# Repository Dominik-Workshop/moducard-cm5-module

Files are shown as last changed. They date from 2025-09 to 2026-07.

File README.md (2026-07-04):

# ModuCard CM5 module

 

<p align="center">
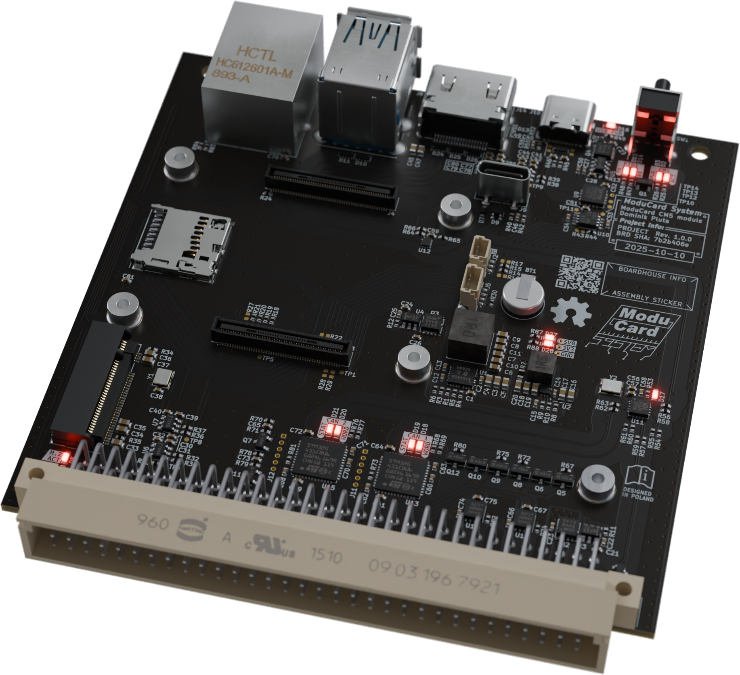
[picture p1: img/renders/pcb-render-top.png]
PCB render top
  
</p>

## Overview

The **ModuCard CM5 Module** is a carrier board for the **Raspberry Pi Compute Module 5**.
It is designed to interface with the  [ModuCard backplane](https://github.com/KoNarRobotics/ModuCard-backplane), to create a more complex electronics system.

The module breaks out selected CM5 interfaces to front-panel connectors and it interfaces with the backplane.

### Key Features

- **Networking:** Gigabit Ethernet (RJ45)
- **Connectivity:** 2x USB 3.0 Type-A ports
- **Display:** 1x Full-size HDMI port
- **Storage:**
  - **Micro SD** card slot (for CM5 Lite variants)
  - **M.2 M-Key** slot (PCIe x1 Gen 3) for NVMe SSDs or AI accelerators.
- **System & Debug:**
  - **USB-C** port (front panel) for serial console access
  - **USB-C** port (vertical) for flashing the CM5 via `rpiboot`.
- **Backplane I/O:**
  - 2x **FD CAN** interfaces with on-board transceivers
  - 1x **USB 2.0**
- **Cooling:** 4-pin JST connector for the CM5 cooling fan.

<p align="center">
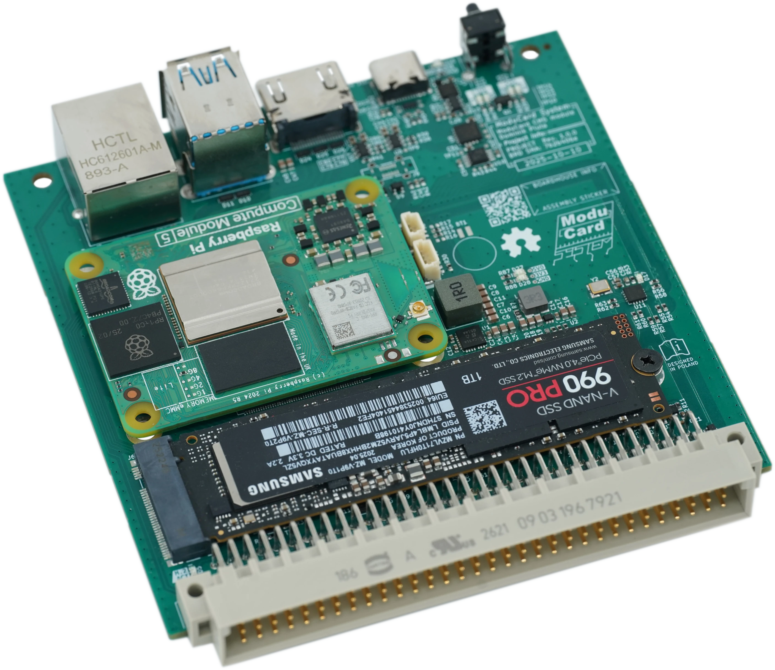
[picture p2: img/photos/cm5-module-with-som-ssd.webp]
Assembled ModuCard CM5 module
  
  <br>
  <em>Assembled ModuCard CM5 Module with Raspberry Pi Compute Module 5 and NVMe SSD.</em>
</p>

## Project Status

**Design:** ✅ → **Fabrication & Assembly:** ✅ → **Bring-up:** ✅

The project is **complete and ready for deployment**. All core features have been validated on physical hardware.

## Used Tools

- [KiCad](https://www.kicad.org/) - Schematic and PCB design

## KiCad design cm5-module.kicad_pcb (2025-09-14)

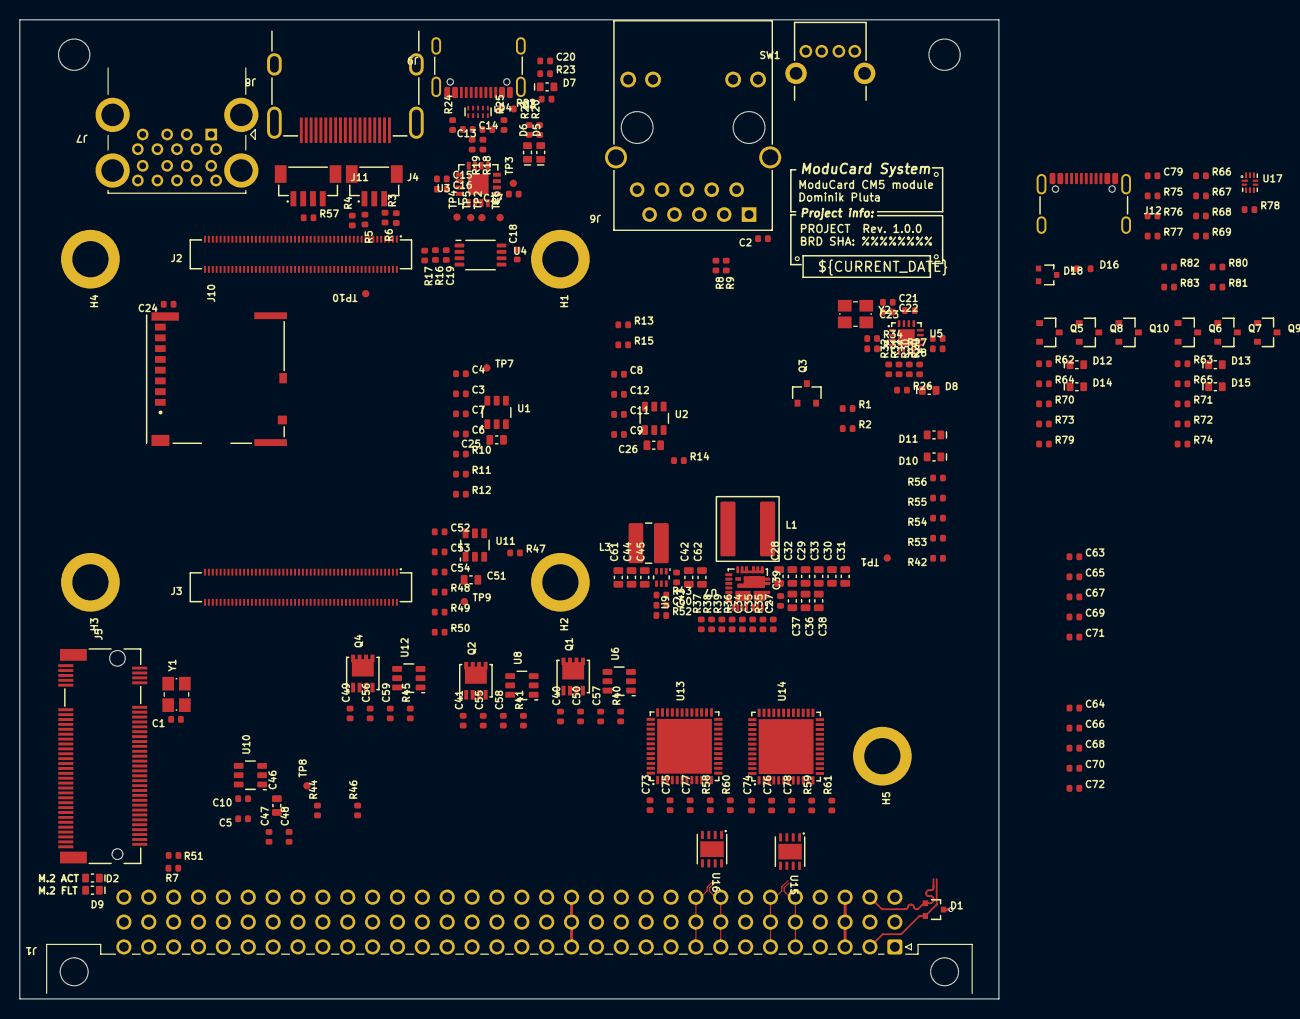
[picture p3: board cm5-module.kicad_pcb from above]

Board: 4 copper layers, 100.0 x 100.0 mm, 240 parts (0 on the bottom side), 205 nets.

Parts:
A1: RPi CM5; CM5
A2: M.2 M-key 2280; Card_M.2-2280-M-key
C1, C2, C3, C4, C5, C8, C9, C16, C17, C18, C19, C20, C22, C24, C27, C39, C40, C41, C43, C48, C49, C50, C54, C55, C56, C57, C58, C59, C63, C64, C65, C66, C67, C68, C69, C70, C71, C72, C73, C74, C75, C76, C77, C78, C79: C-100n-0402; C_0402_1005Metric
C6, C7, C10, C11, C12, C15, C21, C23, C34, C47, C52, C53: C-4u7-0402; C_0402_1005Metric
C13, C14, C60: C-47p-0402; C_0402_1005Metric
C25, C26, C28, C29, C30, C31, C32, C33, C36, C37, C38, C42, C44, C45, C46, C51, C61, C62: C-10u-0603; C_0603_1608Metric
C35: C-1u-0402; C_0402_1005Metric
D1, D18: TPD2E2U06DCKR; SOT-323
D2, D5, D6, D7, D8, D9, D10, D11, D12, D13, D14, D15: LED-R-0603_KT-0603R; LED_0603_1608Metric_R
D3, D16: PESD5Z5; D_SOD-523
D4: PUSB3F96X; SOT1176-1
H1, H2, H3, H4: Spacer_M2.5_H3mm_9774030151R
H5: Spacer_M2.5_H2.5mm_9774025151R
J1: DIN-41612-connector_09031967921; Conn_DIN_41612_09031967921
J2: CM5_1-100_3mm-stack; Conn_Socket_Hirose_DF40_2x50_DF40HC-3.0-100DS-0.4V
J3: CM5_101-200_3mm-stack; Conn_Socket_Hirose_DF40_2x50_DF40HC-3.0-100DS-0.4V
J4: JST_SH_1x3_BM03B-SRSS-TB-LF-SN; Conn_JST_SH_1x3_BM03B-SRSS-TB
J5: Bus_M.2_1-2199230-6; Bus_M.2_Socket_Key_M_TE_1-2199230-6
J6: RJ45_HC612601A-M893-A
J7: USB-A_USB-303WSD-BRY; USB-A_Receptacle_USB-303WSD-BRY
J8: HDMI-A_HDMI-19PIN-043; Conn_HDMI-A_HDMI-19PIN-043
J9, J12: USB-C_USB-310F-B-SU; USB-C-Receptacle_USB-310-B-SU
J10: MicroSD_5033981892
J11: JST_SH_1x4_BM04B-SRSS-TB-LF-SN; Conn_JST_SH_1x4_BM04B-SRSS-TB
L1: L-1u-20A-CJiang-FEXL0650A; L-CJiang-FEXL0650A
L3: L-1u5-6.5A-CJiang-FTC404030S; L-CJiang-FTC404030S
Q1, Q2, Q4: SIS472DN-T1-GE3; PowerPAK-1212-8_Single
Q3, Q5, Q6, Q7, Q10: AO3400A; SOT-23-3
Q8, Q9: AO3401A; SOT-23-3
R1, R2, R3, R4, R5, R6, R10, R16, R17, R27, R28, R29, R30, R31, R32, R33, R34, R42, R44, R47, R50, R53, R54, R66, R67, R68, R69, R82, R83: R-0R-0402; R_0402_1005Metric
R7, R8, R9, R20, R21, R22, R26, R51, R55, R56, R62, R63, R64, R65: R-1k-0402; R_0402_1005Metric
R11, R13, R14, R15, R37, R39, R40, R41, R43, R45, R48, R49, R57, R58, R59, R60, R61, R70, R71, R72, R73, R74, R78, R79, R80, R81: R-10k-0402; R_0402_1005Metric
R12, R46: R-2k2-0402; R_0402_1005Metric
R18, R19: R-22R-0402; R_0402_1005Metric
R23, R75: R-330r-0402; R_0402_1005Metric
R24, R25, R76, R77: R-5k1-0402; R_0402_1005Metric
R35, R36: R-499k-0402; R_0402_1005Metric
R38: R-73k2-0402; R_0402_1005Metric
R52: R-45k3-0402; R_0402_1005Metric
SW1: SW_TL2243
TP1, TP2, TP3, TP4, TP5, TP6, TP7, TP8, TP9, TP10: TP_SMD_0.75mm
U1, U2, U10, U11: AP22615AWU-7; TSOT-23-6
U3: FT230XQ-R; QFN-16-1EP_4x4mm_P0.65mm_EP2.15x2.15mm
U4: NTS0102DP; TSSOP-8_3x3mm_P0.65mm
U5: CH334P; QFN-16-1EP_3x3mm_P0.5mm_EP1.75x1.75mm
U6, U8, U12: LM74700QDBVRQ1; SOT-23-6
U7: SIC431AED-T1-GE3; MLP44-24L_4x4x0.75mm
U9: TPS564247DRLR; SOT-563
U13, U14: STM32G431CBU6; UFQFPN-48-1EP_7x7mm_P0.5mm_EP5.7x5.7mm
U15, U16: TJA1044GTK_3Z; HVSON-8-1EP_3x3mm_P0.65mm_EP1.6x2.4mm
U17: FSUSB42UMX; UFQFN-10_1.4x1.8mm_P0.4mm
Y1: Oscillator_32.768kHz_OK2EL89CJI-111YLC-32.768K; Crystal_SMD_3225-4Pin_3.2x2.5mm
Y2: X322512MSB4SI; Crystal_SMD_3225-4Pin_3.2x2.5mm

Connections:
+3V3: C5.1, C10.2, C44.2, C45.2, C53.2, C54.1, C61.2, C63.1, C64.1, C65.1, C66.1, C67.1, C68.1, C69.1, C70.1, C71.1, C72.1, D9.2 (A), D10.2 (A), D11.2 (A), D12.2 (A), D13.2 (A), D14.2 (A), D15.2 (A), J6.11, J6.14, L3.2, Q8.2 (S), Q9.2 (S), R16.1, R57.2, R58.2, R59.2, R73.2, R74.2, U10.6 (IN), U11.6 (IN), U13.1 (VBAT), U13.20 (VREF+), U13.21 (VDDA), U13.23 (VDD), U13.35 (VDD), U13.48 (VDD), U14.1 (VBAT), U14.20 (VREF+), U14.21 (VDDA), U14.23 (VDD), U14.35 (VDD), U14.48 (VDD), U17.9 (VCC)
+3V3_M2: C1.2, C46.2, C47.2, C48.1, D2.2 (A), J5.2 (3V3), J5.4 (3V3), J5.12 (3V3), J5.14 (3V3), J5.16 (3V3), J5.18 (3V3), J5.70 (3V3), J5.72 (3V3), J5.74 (3V3), U10.1 (OUT), Y1.1 (EN), Y1.4 (VDD)
+5V: C3.1, C6.2, C8.1, C11.2, C23.2, C42.2, C43.1, C57.1, C58.1, C59.1, C62.2, C75.1, C76.1, D8.2 (A), J2.77 (+5V_(Input)), J2.79 (+5V_(Input)), J2.81 (+5V_(Input)), J2.83 (+5V_(Input)), J2.85 (+5V_(Input)), J2.87 (+5V_(Input)), J11.1, Q1.5 (D), Q2.5 (D), Q4.5 (D), R13.1, U1.6 (IN), U2.6 (IN), U5.15 (5V), U6.4 (CATHODE), U8.4 (CATHODE), U9.1 (V_{IN}), U9.5 (EN), U12.4 (CATHODE), U15.3 (VCC), U16.3 (VCC)
+5V_STDBY: C40.1, C50.1, J1.a3, J1.b3, J1.c3, Q1.1 (S), Q1.2 (S), Q1.3 (S), R40.2, U6.6 (ANODE)
+12V: C36.2, C37.2, C38.2, C39.1, J1.a11, J1.a12, J1.b11, J1.b12, J1.c11, J1.c12, R39.2, U7.1 (V_{IN}), U7.2 (V_{IN}), U7.22 (V_{IN}), U7.26 (V_{IN})
+24V: J1.a14, J1.b14, J1.c14
/Backplane/BACKPLANE.D+: D1.2, J1.a2, R31.2
/Backplane/BACKPLANE.D-: D1.1, J1.c2, R32.2
/Backplane/CAN_1.+: J1.a5, J1.b5, J1.c5, U15.7 (CANH)
/Backplane/CAN_1.-: J1.a6, J1.b6, J1.c6, U15.6 (CANL)
/Backplane/CAN_2.+: J1.a8, J1.b8, J1.c8, U16.7 (CANH)
/Backplane/CAN_2.-: J1.a9, J1.b9, J1.c9, U16.6 (CANL)
/CAN to USB 1/EN_TRANSCEIVER: Q5.1 (G), R66.1, R70.2
/CAN to USB 1/RST_MCU: Q10.1 (G), R67.1, R79.2
/CAN to USB 1/RXD: U13.46 (PB8-BOOT0), U15.4 (RXD)
/CAN to USB 1/STAT_LED: R64.1, U13.38 (PA15)
/CAN to USB 1/TXD: U13.47 (PB9), U15.1 (TXD)
/CAN to USB 1/USB.D+: R27.2, U13.34 (PA12)
/CAN to USB 1/USB.D-: R28.2, U13.33 (PA11)
/CAN to USB 1/VIO: C77.1, Q8.3 (D), U15.5 (VIO)
/CAN to USB 1/WORD_LED: R62.1, U13.8 (PA0)
/CAN to USB 1/~RST: C73.1, Q10.3 (D), R58.1, U13.7 (PG10-~RST)
/CAN to USB 2/EN_TRANSCEIVER: Q7.1 (G), R68.1, R72.2
/CAN to USB 2/RST_MCU: Q6.1 (G), R69.1, R71.2
/CAN to USB 2/RXD: U14.46 (PB8-BOOT0), U16.4 (RXD)
/CAN to USB 2/STAT_LED: R65.1, U14.38 (PA15)
/CAN to USB 2/TXD: U14.47 (PB9), U16.1 (TXD)
/CAN to USB 2/USB.D+: R29.2, U14.34 (PA12)
/CAN to USB 2/USB.D-: R30.2, U14.33 (PA11)
/CAN to USB 2/VIO: C78.1, Q9.3 (D), U16.5 (VIO)
/CAN to USB 2/WORD_LED: R63.1, U14.8 (PA0)
/CAN to USB 2/~RST: C74.1, Q6.3 (D), R59.1, U14.7 (PG10-~RST)
/CM5/+1V8_CM5: J2.88 (+1.8V_(Output)), J2.90 (+1.8V_(Output)), R1.1
/CM5/+3V3_CM5: J2.84 (+3.3V_(Output)), J2.86 (+3.3V_(Output)), R2.1
/CM5/CC1: D4.5 (CH4), D4.6 (CH4), J2.94 (CC1), J9.A5 (CC1), R25.2
/CM5/CC2: D4.1 (CH1), D4.10 (CH1), J2.96 (CC2), J9.B5 (CC2), R24.2
/CM5/CM5_RX: J4.1, R5.1
/CM5/CM5_TX: J4.3, R6.1
/CM5/CONSOLE.RX: R3.2, R6.2, U4.4 (A_{2})
/CM5/CONSOLE.TX: R4.2, R5.2, U4.5 (A_{1})
/CM5/ETH.D1+: J2.12 (Ethernet_Pair0_P), J6.2 (TD1+)
/CM5/ETH.D1-: J2.10 (Ethernet_Pair0_N), J6.3 (TD1-)
/CM5/ETH.D2+: J2.4 (Ethernet_Pair1_P), J6.4 (TD2+)
/CM5/ETH.D2-: J2.6 (Ethernet_Pair1_N), J6.7 (TD2-)
/CM5/ETH.D3+: J2.11 (Ethernet_Pair2_P), J6.5 (TD3+)
/CM5/ETH.D3-: J2.9 (Ethernet_Pair2_N), J6.6 (TD3-)
/CM5/ETH.D4+: J2.3 (Ethernet_Pair3_P), J6.8 (TD4+)
/CM5/ETH.D4-: J2.5 (Ethernet_Pair3_N), J6.9 (TD4-)
/CM5/ETH.LED_ACT: J2.15 (Ethernet_nLED3), R9.2
/CM5/ETH.LED_LINK: J2.17 (Ethernet_nLED2), R8.2
/CM5/FAN_PWM: J2.19 (FAN_PWM), J11.2, R57.1
/CM5/FAN_TACHO: J2.16 (FAN_TACHO), J11.4
/CM5/GPIO_VREF: J2.78 (GPIO_VREF), R1.2, R2.2, R17.1
/CM5/HDMI_0.CEC: J3.51 (HDMI0_CEC), J8.13 (CEC)
/CM5/HDMI_0.CLK+: J3.88 (HDMI0_CLK_P), J8.10 (CK+)
/CM5/HDMI_0.CLK-: J3.90 (HDMI0_CLK_N), J8.12 (CK-)
/CM5/HDMI_0.D0+: J3.82 (HDMI0_TX0_P), J8.7 (D0+)
/CM5/HDMI_0.D0-: J3.84 (HDMI0_TX0_N), J8.9 (D0-)
/CM5/HDMI_0.D1+: J3.76 (HDMI0_TX1_P), J8.4 (D1+)
/CM5/HDMI_0.D1-: J3.78 (HDMI0_TX1_N), J8.6 (D1-)
/CM5/HDMI_0.D2+: J3.70 (HDMI0_TX2_P), J8.1 (D2+)
/CM5/HDMI_0.D2-: J3.72 (HDMI0_TX2_N), J8.3 (D2-)
/CM5/HDMI_0.HOTPLUG: J3.53 (HDMI0_HOTPLUG), J8.19 (HPD)
/CM5/HDMI_0.SCL: J3.100 (HDMI0_SCL), J8.15 (SCL)
/CM5/HDMI_0.SDA: J3.99 (HDMI0_SDA), J8.16 (SDA)
/CM5/PCIe.REFCLK+: J3.10 (PCIe_CLK_P), J5.55 (REFCLK_P)
/CM5/PCIe.REFCLK-: J3.12 (PCIe_CLK_N), J5.53 (REFCLK_N)
/CM5/PCIe.RX0+: J3.16 (PCIe_RX_P), J5.43 (PER0_P)
/CM5/PCIe.RX0-: J3.18 (PCIe_RX_N), J5.41 (PER0_N)
/CM5/PCIe.TX0+: J3.22 (PCIe_TX_P), J5.49 (PET0_P)
/CM5/PCIe.TX0-: J3.24 (PCIe_TX_N), J5.47 (PET0_N)
/CM5/PCIe_PWR_EN: J3.6 (PCIE_PWR_EN), R44.1
/CM5/PMIC_EN: J2.99 (PMIC_ENABLE), TP1.1
/CM5/PWR_BTN: J2.92 (PWR_BUT), SW1.1 (BOTTOM_SW_1)
/CM5/SD_CARD.CLK: J2.57 (SD_CLK), J10.5 (CLK)
/CM5/SD_CARD.CMD: J2.62 (SD_CMD), J10.3 (CMD)
/CM5/SD_CARD.DAT0: J2.63 (SD_DAT0), J10.7 (DAT0)
/CM5/SD_CARD.DAT1: J2.67 (SD_DAT1), J10.8 (DAT1)
/CM5/SD_CARD.DAT2: J2.69 (SD_DAT2), J10.1 (DAT2)
/CM5/SD_CARD.DAT3: J2.61 (SD_DAT3), J10.2 (DAT3/CD)
/CM5/SD_PWR_ON: J2.75 (SD_PWR_ON), R50.1
/CM5/UART2_RX: J2.34 (GPIO5), R4.1
/CM5/UART2_TX: J2.54 (GPIO4), R3.1
/CM5/USB_SS_0.D+: J3.34 (USB3-0-D_P), J7.3 (D+)
/CM5/USB_SS_0.D-: J3.36 (USB3-0-D_N), J7.2 (D-)
/CM5/USB_SS_0.RX+: J3.30 (USB3-0-RX_P), J7.6 (SSRX+)
/CM5/USB_SS_0.RX-: J3.28 (USB3-0-RX_N), J7.5 (SSRX-)
/CM5/USB_SS_0.TX+: J3.42 (USB3-0-TX_P), J7.9 (SSTX+)
/CM5/USB_SS_0.TX-: J3.40 (USB3-0-TX_N), J7.8 (SSTX-)
/CM5/USB_SS_1.D+: J3.63 (USB3-1-D_P), J7.12 (D+)
/CM5/USB_SS_1.D-: J3.65 (USB3-1-D_N), J7.11 (D-)
/CM5/USB_SS_1.RX+: J3.59 (USB3-1-RX_P), J7.15 (SSRX+)
/CM5/USB_SS_1.RX-: J3.57 (USB3-1-RX_N), J7.14 (SSRX-)
/CM5/USB_SS_1.TX+: J3.71 (USB3-1-TX_P), J7.18 (SSTX+)
/CM5/USB_SS_1.TX-: J3.69 (USB3-1-TX_N), J7.17 (SSTX-)
/CM5/VBUS_EN: J3.11 (VBUS_EN), R10.1
/CM5/~BT_DIS: J2.91 (BT_nDisable), R54.2
/CM5/~EEPROM_WP: J2.20 (EEPROM_nWP), R42.2
/CM5/~LED_ACT: J2.21 (LED_nACT), R56.1
/CM5/~LED_PWR: J2.95 (LED_nPWR), R55.1
/CM5/~PCIe_CLKREQ: J3.2 (PCIe_nCLKREQ), J5.52 (~CLKREQ)
/CM5/~PCIe_PERST: J3.9 (PCIe_nRST), J5.50 (~PERST)
/CM5/~PCIe_WAKE: J3.4 (PCIE_nWAKE), J5.54 (~PEWAKE)
/CM5/~RPIBOOT: J2.93 (nRPIBOOT), SW1.2 (BOTTOM_SW_1)
/CM5/~WiFi_DIS: J2.89 (WiFi_nDisable), R53.2
/HDMI/EN: R13.2, U2.4 (EN)
/HDMI/FLG: R14.1, U2.3 (FLG)
/HDMI/HDMI_+5V: C9.1, C12.2, C26.2, J8.18 (+5V), R14.2, U2.1 (OUT)
/HDMI/ISET: R15.1, U2.5 (ISET)
/M.2/EN: R44.2, TP8.1, U10.4 (EN)
/M.2/ISET: R46.1, U10.5 (ISET)
/M.2/LED: J5.10 (LED), R7.1
/M.2/SUSCLK: R47.2, Y1.3 (OUT)
/M.2/SUSCLK_R: J5.68 (SUSCLK), R47.1
/M.2/~FLG: R51.1, U10.3 (~FLG)
/Power/5V: C28.2, C29.2, C30.2, C31.2, C32.2, C33.2, C41.1, C55.1, L1.2, Q2.1 (S), Q2.2 (S), Q2.3 (S), Q3.1 (G), R38.1, R41.2, U7.18 (V_{OUT}), U8.6 (ANODE)
/Power/5V_BOOT: C27.2, U7.23 (BOOT)
/Power/5V_EN: R39.1, U7.19 (EN)
/Power/5V_FB: R37.2, R38.2, U7.17 (FB)
/Power/5V_MODE1: R35.2, U7.21 (MODE1)
/Power/5V_MODE2: R36.2, U7.20 (MODE2)
/Power/5V_PHASE: C27.1, U7.24 (PHASE)
/Power/5V_SW: L1.1, U7.5 (SW), U7.6 (SW), U7.7 (SW), U7.8 (SW), U7.9 (SW)
/Power/5V_USB_IN: C15.2, C16.2, C49.1, C56.1, D3.1 (C), J9.A4 (VBUS), J9.A9 (VBUS), J9.B4 (VBUS), J9.B9 (VBUS), Q4.1 (S), Q4.2 (S), Q4.3 (S), R22.2, R45.2, U3.10 (V_{CC}), U12.6 (ANODE)
/Power/5V_VDD: C35.2, U7.15 (V_{DD})
/Power/5V_VDRV: C34.2, U7.12 (V_{DRV})
/Power/Ideal diode 0/~DISABLE: R40.1, U6.3 (EN)
/Power/Ideal diode 1/~DISABLE: R41.1, U8.3 (EN)
/Power/Ideal diode 2/~DISABLE: Q3.3 (D), R45.1, U12.3 (EN)
/SD card/EN: R50.2, TP9.1, U11.4 (EN)
/SD card/FLG: R48.1, U11.3 (FLG)
/SD card/ISET: R49.1, U11.5 (ISET)
/USB console/FTDI_CBUS0: TP4.1, U3.12 (CBUS0)
/USB console/FTDI_CBUS3: TP5.1, U3.14 (CBUS3)
/USB console/FTDI_LED_RX: D5.1 (C), U3.11 (CBUS1)
/USB console/FTDI_LED_TX: D6.1 (C), U3.5 (CBUS2)
/USB console/FTDI_VCCIO: C17.2, C18.2, R20.2, R21.2, U3.1 (V_{CCIO}), U3.8 (3V3_{OUT}), U3.9 (~RESET), U4.7 (VCC_{B})
/USB console/USB_D+: C13.2, D4.4 (CH3), D4.7 (CH3), J9.A6 (D+), J9.B6 (D+), R18.1
/USB console/USB_D-: C14.2, D4.2 (CH2), D4.9 (CH2), J9.A7 (D-), J9.B7 (D-), R19.1
/USB hub/USB_1_R.D+: R27.1, U5.10 (DP1)
/USB hub/USB_1_R.D-: R28.1, U5.9 (DM1)
/USB hub/USB_2_R.D+: R29.1, U5.8 (DP2)
/USB hub/USB_2_R.D-: R30.1, U5.7 (DM2)
/USB hub/USB_3_R.D+: R31.1, U5.6 (DP3)
/USB hub/USB_3_R.D-: R32.1, U5.5 (DM3)
/USB hub/USB_4_R.D+: R33.1, U5.4 (DP4)
/USB hub/USB_4_R.D-: R34.1, U5.3 (DM4)
/USB hub/USB_HUB.D+: R82.2, U5.12 (DPU)
/USB hub/USB_HUB.D-: R83.2, U5.11 (DMU)
/USB hub/XI: U5.2 (XI), Y2.3
/USB hub/XO: U5.1 (XO), Y2.1
/USB switch/SEL: D16.1 (C), J12.A4 (VBUS), J12.A9 (VBUS), J12.B4 (VBUS), J12.B9 (VBUS), R78.2
/USB switch/USB_2.D+: D18.1, J12.A6 (D+), J12.B6 (D+)
/USB switch/USB_2.D-: D18.2, J12.A7 (D-), J12.B7 (D-)
/USB/+VBUS: C4.1, C7.2, C25.2, J7.1 (VBUS), J7.10 (VBUS), R11.2, U1.1 (OUT)
/USB/EN: R10.2, TP7.1, U1.4 (EN)
/USB/FLG: R11.1, U1.3 (FLG)
/USB/ISET: R12.1, U1.5 (ISET)
GND: C1.1, C2.1, C3.2, C4.2, C5.2, C6.1, C7.1, C8.2, C9.2, C10.1, C11.1, C12.1, C13.1, C14.1, C15.1, C16.1, C17.1, C18.1, C19.1, C20.1, C21.1, C22.1, C23.1, C24.1, C25.1, C26.1, C28.1, C29.1, C30.1, C31.1, C32.1, C33.1, C34.1, C35.1, C36.1, C37.1, C38.1, C39.2, C42.1, C43.2, C44.1, C45.1, C46.1, C47.1, C48.2, C50.2, C51.1, C52.1, C53.1, C54.2, C55.2, C56.2, C57.2, C58.2, C59.2, C61.1, C62.1, C63.2, C64.2, C65.2, C66.2, C67.2, C68.2, C69.2, C70.2, C71.2, C72.2, C73.2, C74.2, C75.2, C76.2, C77.2, C78.2, C79.1, D1.3, D3.2 (A), D4.3 (GND), D4.8 (GND), D7.1 (C), D16.2 (A), D18.3, H1.1, H2.1, H3.1, H4.1, H5.1, J1.a1, J1.a4, J1.a7, J1.a10, J1.a13, J1.a15, J1.a32, J1.b1, J1.b2, J1.b4, J1.b7, J1.b10, J1.b13, J1.b15, J1.b32, J1.c1, J1.c4, J1.c7, J1.c10, J1.c13, J1.c15, J1.c32, J2.1 (GND), J2.2 (GND), J2.7 (GND), J2.8 (GND), J2.13 (GND), J2.14 (GND), J2.22 (GND), J2.23 (GND), J2.32 (GND), J2.33 (GND), J2.42 (GND), J2.43 (GND), J2.52 (GND), J2.53 (GND), J2.59 (GND), J2.60 (GND), J2.65 (GND), J2.66 (GND), J2.71 (GND), J2.74 (GND), J2.98 (GND), J3.7 (GND), J3.8 (GND), J3.13 (GND), J3.14 (GND), J3.19 (GND), J3.20 (GND), J3.25 (GND), J3.26 (GND), J3.31 (GND), J3.32 (GND), J3.37 (GND), J3.38 (GND), J3.44 (GND), J3.50 (GND), J3.55 (GND), J3.56 (GND), J3.61 (GND), J3.62 (GND), J3.67 (GND), J3.68 (GND), J3.73 (GND), J3.74 (GND), J3.79 (GND), J3.80 (GND), J3.85 (GND), J3.86 (GND), J3.91 (GND), J3.92 (GND), J3.97 (GND), J3.98 (GND), J4.2, J4.MP, J5.1 (GND), J5.3 (GND), J5.9 (GND), J5.15 (GND), J5.21 (GND), J5.27 (GND), J5.33 (GND), J5.39 (GND), J5.45 (GND), J5.51 (GND), J5.57 (GND), J5.71 (GND), J5.73 (GND), J5.75 (GND), J5.MP1 (MP), J5.MP2 (MP), J6.10 (GND), J6.SH, J7.4 (GND), J7.7 (DRAIN), J7.13 (GND), J7.16 (DRAIN), J7.19 (SHIELD), J8.2 (D2S), J8.5 (D1S), J8.8 (D0S), J8.11 (CKS), J8.17 (GND), J8.SH, J9.A1 (GND), J9.A12 (GND), J9.B1 (GND), J9.B12 (GND), J10.6 (VSS), J10.11 (SHIELD), J11.3, J11.MP, J12.A1 (GND), J12.A12 (GND), J12.B1 (GND), J12.B12 (GND), Q3.2 (S), Q5.2 (S), Q6.2 (S), Q7.2 (S), Q10.2 (S), R12.2, R15.2, R23.1, R24.1, R25.1, R35.1, R36.1, R37.1, R42.1, R43.1, R46.2, R49.2, R53.1, R54.1, R60.1, R61.1, R70.1, R71.1, R72.1, R75.1, R76.1, R77.1, R79.1, R80.1, R81.1, SW1.3 (BOTTOM_SW_2), SW1.4 (BOTTOM_SW_2), SW1.5 (SH), SW1.6 (SH), TP6.1, U1.2 (GND), U2.2 (GND), U3.3 (GND), U3.13 (GND), U3.17 (GND), U4.2 (GND), U5.17 (GND), U6.2 (GND), U7.3 (P_{GND}), U7.4 (P_{GND}), U7.13 (P_{GND}), U7.16 (A_{GND}), U7.25 (A_{GND}), U7.27 (P_{GND}), U8.2 (GND), U9.3 (GND), U9.4 (AGND), U10.2 (GND), U11.2 (GND), U12.2 (GND), U13.49 (VSS), U14.49 (VSS), U15.2 (GND), U15.9 (GND), U16.2 (GND), U16.9 (GND), U17.3 (GND), Y1.2 (GND), Y2.2 (SH), Y2.4 (SH)
unnamed: D2.1 (C), R7.2
unnamed: D5.2 (A), R20.1
unnamed: D6.2 (A), R21.1
unnamed: D7.2 (A), R22.1
unnamed: D8.1 (C), R26.2
unnamed: D9.1 (C), R51.2
unnamed: D10.1 (C), R55.2
unnamed: D11.1 (C), R56.2
unnamed: D12.1 (C), R62.2
unnamed: D13.1 (C), R63.2
unnamed: D14.1 (C), R64.2
unnamed: D15.1 (C), R65.2
unnamed: J2.18 (Ethernet_SYNC_OUT), TP10.1
unnamed: J2.44 (GPIO10), R66.2
unnamed: J2.38 (GPIO11), R67.2
unnamed: J2.31 (GPIO12), R68.2
unnamed: J2.28 (GPIO13), R69.2
unnamed: C2.2, J6.1 (CT)
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

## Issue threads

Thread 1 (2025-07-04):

Schematic: Design CM5 module

Dominik-Workshop, 2025-07-04:
Design a module **schematic** for the Raspberry Pi Compute Module 5. The goal is a compact board that implements the core I/O features listed below, using the official CM5 IO board as a design reference.

---
**Core Requirements**
- **USB:**
    2x USB 3.0 Type-A ports.
    ~~2x USB 2.0 Type-A ports.~~
- **Display:** 1x Full-size HDMI port.
- **Networking:** 1x RJ45 Gigabit Ethernet port.
- **Storage:**
    - 1x MicroSD card slot.
    - 1x PCIe M.2 M-Key slot for NVMe SSDs.
- **Interfacing:**
    - 1x USB-C for console access.
    - 2x CAN bus interface with an external transceiver, connecting to a backplane connector.

**Key References**
- **CM5 Datasheet:** [https://datasheets.raspberrypi.com/cm5/cm5-datasheet.pdf](https://datasheets.raspberrypi.com/cm5/cm5-datasheet.pdf)
- **CM5 IO Board Design Files:** [https://pip.raspberrypi.com/categories/1098-design-files](https://pip.raspberrypi.com/categories/1098-design-files)

Dominik-Workshop, 2025-09-14:
Schematic is mostly done.

Closed 2025-09-14.

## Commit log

2025-07-05 [#1] Init project
    [2usb3_0.kicad_sch, backplane.kicad_sch, cm5-module.kicad_pcb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]
2025-07-22 [#1] WIP: Change components to ones from the global library, refactor schematic
    [2usb3_0.kicad_sch, backplane.kicad_sch, cm5-module.kicad_pcb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]
2025-08-01 [#1] Change components to ones from the global library, add debug console, refactor schematic
    [2usb3_0.kicad_sch, backplane.kicad_sch, cm5-module.kicad_pcb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]
2025-08-01 [#1] Add bus colors, rename PCIe signals
    [cm5-module.kicad_sch, cm5.kicad_sch, m2.kicad_sch]
2025-08-01 [#1] Add debug UART connector
    [cm5-module.kicad_sch, cm5.kicad_sch, usb-console.kicad_sch]
2025-08-08 [#1] Add level shifter for UART debug, update footprints from library
    [backplane.kicad_sch, cm5-module.kicad_pcb, cm5-module.kicad_sch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]
2025-08-19 [#1] Re-annotate schematic
    [2usb3_0.kicad_sch, backplane.kicad_sch, cm5.kicad_sch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]
2025-08-22 [#1] Add power section
    [cm5-module.kicad_sch, cm5.kicad_sch, power.kicad_sch]
2025-08-22 [#1] Sync PCB with schematic, draft component placement
    [backplane.kicad_sch, cm5-module.kicad_pcb, cm5.kicad_sch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]
2025-08-30 [#1] WIP: Refactor schematic
    [2usb3_0.kicad_sch, backplane.kicad_sch, can-to-usb.kicad_sch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]
2025-09-11 [#1] Finish schematic design of the 3V3 DC-DC converter
    [cm5-module.kicad_pcb, power.kicad_sch]
2025-09-11 [#1] Update CM5 connectors symbols, connect its misc pins
    [cm5-module.kicad_sch, cm5.kicad_sch]
2025-09-12 [#1] Add cooling fan connector
    [cm5-module.kicad_pcb, cm5.kicad_sch]
2025-09-13 [#1] Add USB to CAN schematic, add power flags to 5V and 3V3
    [can-to-usb.kicad_sch, cm5-module.kicad_pcb, cm5-module.kicad_sch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]
2025-09-13 [#1] Rename USB schematic sheet
    [cm5-module.kicad_sch, usb.kicad_sch]
2025-09-14 [#1] Add USB switch and 0R to USB hub data lines, minor schematic refactor
    [can-to-usb.kicad_sch, cm5-module.kicad_pcb, cm5-module.kicad_sch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]
2025-09-15 [#3] Align PCB to grid, start placement of key components
    Position the M.2 connector, try positioning of front panel connectors
    [cm5-module.kicad_pcb]
2025-09-20 [#3] Fix 3V3 DC-DC converter schematic, change one USB-C to a vertical one, start layout
    [can-to-usb.kicad_sch, cm5-module.kicad_pcb, power.kicad_sch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]
2025-09-20 [#3] Adjust front panel mounting holes positioning and rails keepout area
    [cm5-module.kicad_pcb]
2025-09-20 [#3] Position front panel connectors
    [cm5-module.kicad_pcb]
2025-09-20 [#3] Add TVS, route HDMI and fanout ETH
    [cm5-module.kicad_pcb, hdmi.kicad_sch, rj45.kicad_sch]
2025-09-21 [#3] Layout HDMI, PCIe and ETH differential pairs
    [cm5-module.kicad_pcb, usb-switch.kicad_sch, usb.kicad_sch]
2025-09-21 [#3] Layout USB power
    [cm5-module.kicad_pcb, m2.kicad_sch, usb.kicad_sch]
2025-09-27 [#3] Continue layout, minor schematic fixes, add power switch for CAN transceiver 5V rail
    [can-to-usb.kicad_sch, cm5-module.kicad_pcb, hdmi.kicad_sch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]
2025-09-27 [#3] WIP: Clear ERC, re-annotate schematic
    [can-to-usb.kicad_sch, cm5-module.kicad_pcb, cm5-module.kicad_sch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]
2025-09-27 [#3] Layout DC-DC converters
    [cm5-module.kicad_pcb]
2025-09-27 [#3] Add 0R to DC-DC outputs, add 5V->3V3 power sequencing
    [cm5-module.kicad_pcb, power.kicad_sch]
2025-09-27 [#3] Add CM5 RTC battery
    [backplane.kicad_sch, cm5-module.kicad_pcb, cm5.kicad_sch]
2025-09-27 [#3] WIP: Layout power and USB console
    [cm5-module.kicad_pcb]
2025-09-28 [#3] Start USB layout
    [cm5-module.kicad_pcb, usb-console.kicad_sch, usb-switch.kicad_sch]
2025-09-28 [#3] Move the 5V DC-DC ideal diode, position fan and debug JST connectors
    [cm5-module.kicad_pcb]
2025-09-28 [#3] Layout SD card connector
    NOTE: Used 0.3mm traces instead of 0.35mm ones on SDIO lines due to
    limited space
    [cm5-module.kicad_pcb]
2025-09-29 [#3] Layout M.2 power
    [cm5-module.kicad_pcb, cm5.kicad_sch]
2025-10-04 [#3] Layout USB
    [cm5-module.kicad_pcb, cm5-module.kicad_sch, usb.kicad_sch]
2025-10-05 [#3] Layout USB to CAN converter and remaining low speed signals
    [cm5-module.kicad_pcb, cm5.kicad_sch]
2025-10-05 [#3] Change schematic sheets order
    [cm5-module.kicad_sch, cm5.kicad_sch, power.kicad_sch]
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2025-10-05 [#3] Position components designators on PCB
    [cm5-module.kicad_pcb]
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2025-10-05 [#3] Improve LEDs descriptions on the PCB
    [cm5-module.kicad_pcb]
2025-10-05 [#3] Add via stitching
    [cm5-module.kicad_pcb]
2025-10-06 [#3] Add GND pours on top and bottom
    [cm5-module.kicad_pcb, cm5-module.kicad_sch, cm5.kicad_sch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]
2025-10-07 [#3] Add 5V and 3V3 power indicator LEDs and test-points
    [cm5-module.kicad_pcb, power.kicad_sch]
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2025-10-08 [#5] Move the KiCad project to pcb folder
    [backplane.kicad_sch, can-to-usb.kicad_sch, cm5-module.kicad_sch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]
2025-10-08 [#5] Assign GND net class
    [backplane.kicad_sch]
2025-10-08 [#5] Refactor the schematic
    [can-to-usb.kicad_sch, cm5.kicad_sch, hdmi.kicad_sch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]
2025-10-09 [#5] Disable 5V_STDBY when main 5V rail is present
    [power.kicad_sch]
2025-10-09 [#5] Add decoupling capacitor closer to the SD card, update programming connector from library
    [sd-card.kicad_sch]
2025-10-09 [#5] Add more 3V3 zone connecting vias, convert text in logos to polygons, update date
    [backplane.kicad_sch, can-to-usb.kicad_sch, cm5-module.kicad_sch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]
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
